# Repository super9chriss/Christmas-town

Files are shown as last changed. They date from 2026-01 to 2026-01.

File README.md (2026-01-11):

# "Smart"christmas town
A ESP32 C6 based Christmas town which connects to homeautomation to be able to remotly turn on and off the christmas lights
<div align="center">
  

</div>

## Features

* **Microcontroller:** ESP32-C6-Zero
* **Power Input:** 12V DC
* **supported** it works with 3 3V, 2 4.5V and one 12V houses/street lights but you can add more or use less based on youre christmas town
* **Connectivity:** USB-C receptacle for easy firmware flashing.

## PCB and schematic
| **PCB Layout** | **Schematic** |
| :---: | :---: |
||

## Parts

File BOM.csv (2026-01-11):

Description | quantity | price | link
LCSC parts | 1 | 3.71 + 3 (handeling) | see under here
esp32-c6 | 1 | 5.99 | https://nl.aliexpress.com/item/1005007349377720.html?mp=1
12V adapter | 1 | 2.62 | http://nl.aliexpress.com/item/1005007264933490.html?mp=1
PCB | 1 | 3.01 | https://cart.jlcpcb.com/quote?stencilLayer=2&stencilWidth=100&stencilLength=100&stencilCounts=5&plateType=1
 | total: | ? 18.33 ÷ $22
LCSC parts:
Index | LCSC# | MPN | Manufacturer | Package | Customer # | Description | RoHS | Quantity | MOQ | Multiple | Unit Price(?) | Extended Price(?) | Product Link
1 | C85864 | GCM188R71H104KA57D | muRata | 603 | C3,C6 | 100nF ñ10% 50V Ceramic Capacitor X7R 0603 | yes | 50 | 50 | 50 | 0.0096 | 0.48 | https://www.lcsc.com/product-detail/C85864.html
2 | C55722 | 0603CG101F500NT | FH | 603 | C4,C7 | 100pF ñ1% 50V Ceramic Capacitor C0G 0603 | yes | 50 | 50 | 50 | 0.0089 | 0.45 | https://www.lcsc.com/product-detail/C55722.html
3 | C95204 | RT0603BRD0710KL | YAGEO | 603 | R2,R4 | 100mW 10kê 75V Thin Film Resistor ñ25ppm/? ñ0.1% 0603 Chip Resistor - Surface Mount RoHS | yes | 20 | 20 | 20 | 0.0188 | 0.38 | https://www.lcsc.com/product-detail/C95204.html
4 | C70225 | 0603X106K160NT | FH | 603 | C1,C5 | 10uF ñ10% 16V Ceramic Capacitor X5R 0603 | yes | 10 | 10 | 10 | 0.0196 | 0.2 | https://www.lcsc.com/product-detail/C70225.html
5 | C142104 | LVS808040-100M-N | Chilisin | SMD,8x8mm | L1,L2 | 3.42A 10uH ñ20% 49.4mê Magnetic Shielded Inductor SMD,8x8mm Fixed Inductors RoHS | yes | 5 | 5 | 5 | 0.0997 | 0.5 | https://www.lcsc.com/product-detail/C142104.html
6 | C21190 | 0603WAF1001T5E | UNI-ROYAL | 603 | R5,R6,R7,R8 | 1kê ñ1% 100mW 0603 Thick Film Resistor | yes | 100 | 100 | 100 | 0.0011 | 0.11 | https://www.lcsc.com/product-detail/C21190.html
7 | C60077 | 0603X226M100NT | FH | 603 | C2,C2.1,C2.2,C8 | 22uF ñ20% 10V Ceramic Capacitor X5R 0603 | yes | 10 | 10 | 10 | 0.0143 | 0.14 | https://www.lcsc.com/product-detail/C60077.html
8 | C22967 | 0603WAF2702T5E | UNI-ROYAL | 603 | R3 | 27kê ñ1% 100mW 0603 Thick Film Resistor | yes | 100 | 100 | 100 | 0.0012 | 0.12 | https://www.lcsc.com/product-detail/C22967.html
9 | C23196 | 0603WAF5102T5E | UNI-ROYAL | 603 | R1 | 51kê ñ1% 100mW 0603 Thick Film Resistor | yes | 100 | 100 | 100 | 0.0011 | 0.11 | https://www.lcsc.com/product-detail/C23196.html
10 | C2071868 | AP63200WU-7 | DIODES | TSOT-23-6 | U1,U2 | 500kHz Buck Adjustable 2A TSOT-23-6 Voltage Regulators - DC DC Switching Regulators RoHS | yes | 2 | 1 | 1 | 0.3471 | 0.69 | https://www.lcsc.com/product-detail/C2071868.html
11 | C118536 | 2N2222A | ST(Semtech) | TO-92 | Q1,Q2,Q3,Q4 | Bipolar (BJT) Transistor NPN 40V 600mA 250MHz 625mW Through Hole TO-92 | yes | 20 | 20 | 20 | 0.0264 | 0.53 | https://www.lcsc.com/product-detail/C118536.html

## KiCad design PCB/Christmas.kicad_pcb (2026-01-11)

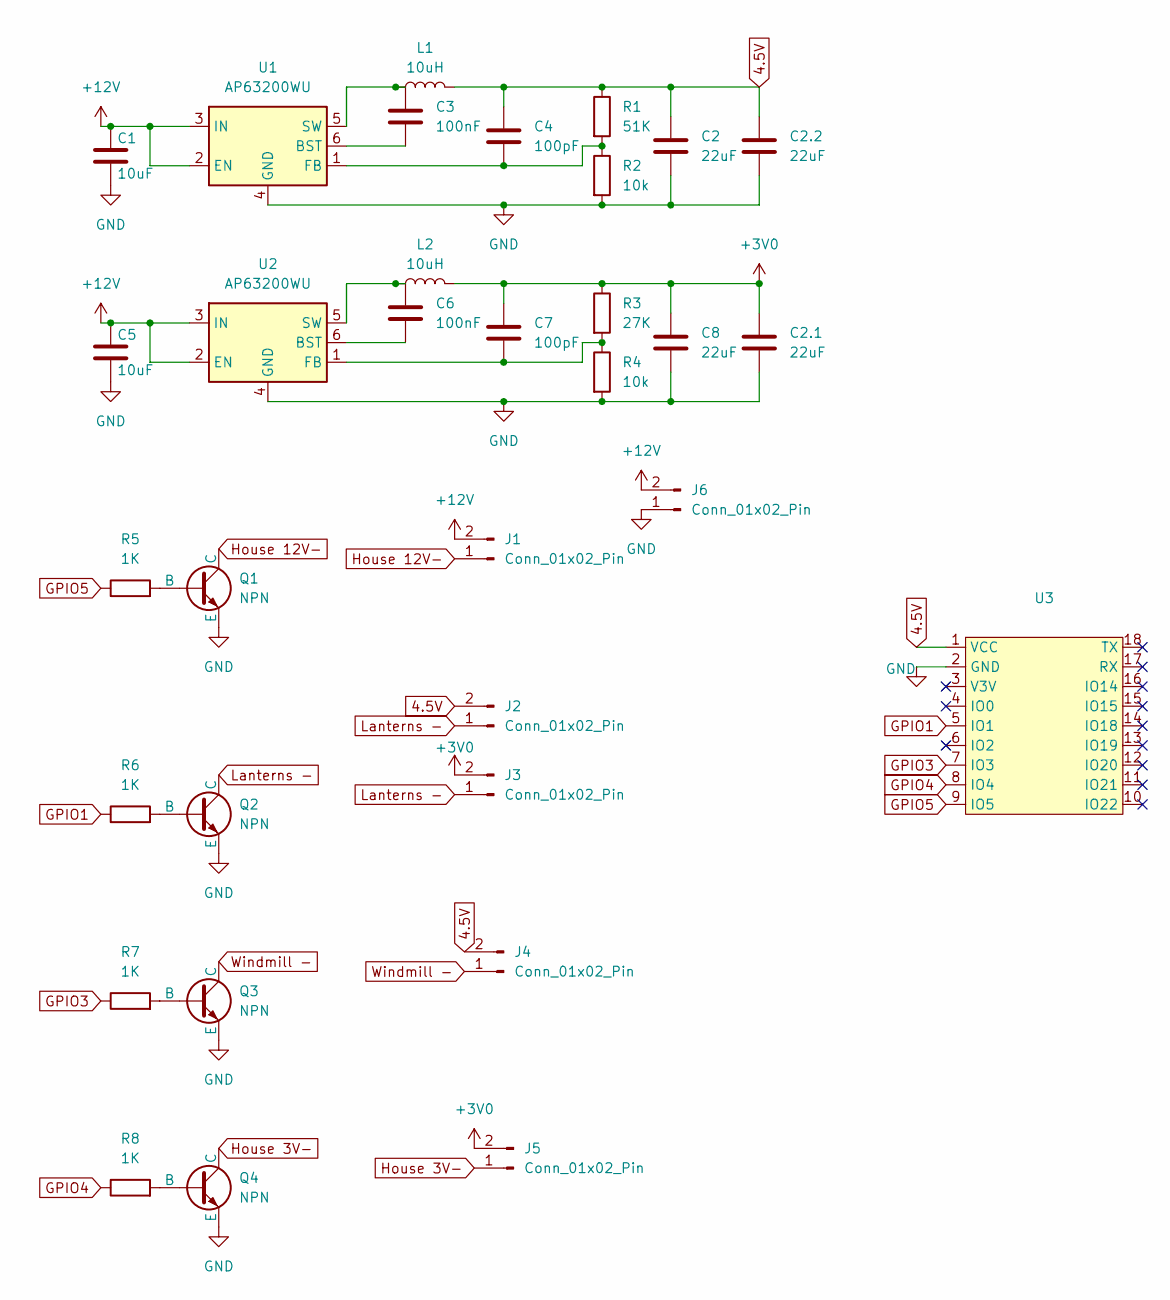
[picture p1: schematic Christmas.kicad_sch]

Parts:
C1, C5: 10uF; C_0603_1608Metric
C2, C2.1, C2.2, C8: 22uF; C_0603_1608Metric
C3, C6: 100nF; C_0603_1608Metric
C4, C7: 100pF; C_0603_1608Metric
J1, J2, J3, J4, J5, J6: Conn_01x02_Pin; SolderWire-0.1sqmm_1x02_P3.6mm_D0.4mm_OD1mm
L1, L2: 10uH; L_Bourns-SRN8040_8x8.15mm
Q1, Q2, Q3, Q4: NPN; TO92254P470H750-3
R1: 51K; R_0603_1608Metric
R2, R4: 10k; R_0603_1608Metric
R3: 27K; R_0603_1608Metric
R5, R6, R7, R8: 1K; R_0603_1608Metric
U1, U2: AP63200WU; TSOT-23-6_HandSoldering
U3: Waveshare-ESP32-C6-Zero

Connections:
4.5V: C2.1, C2.2.1, C4.1, J2.2, J4.2, L1.2, R1.1, U3.1 (VCC)
+3V0: C2.1.1, C7.1, C8.1, J3.2, J5.2, L2.2, R3.1
+12V: C1.1, C5.1, J1.2, J6.2, U1.2 (EN), U1.3 (IN), U2.2 (EN), U2.3 (IN)
GND: C1.2, C2.2, C2.1.2, C2.2.2, C5.2, C8.2, J6.1, Q1.3 (E), Q2.3 (E), Q3.3 (E), Q4.3 (E), R2.2, R4.2, U1.4 (GND), U2.4 (GND), U3.2 (GND)
GPIO1: R6.1, U3.5 (IO1)
GPIO3: R7.1, U3.7 (IO3)
GPIO4: R8.1, U3.8 (IO4)
GPIO5: R5.1, U3.9 (IO5)
House 3V-: J5.1, Q4.1 (C)
House 12V-: J1.1, Q1.1 (C)
Lanterns -: J2.1, J3.1, Q2.1 (C)
unnamed: Q1.2 (B), R5.2
unnamed: Q2.2 (B), R6.2
unnamed: Q3.2 (B), R7.2
unnamed: Q4.2 (B), R8.2
unnamed: C3.2, U1.6 (BST)
unnamed: C4.2, R1.2, R2.1, U1.1 (FB)
unnamed: C3.1, L1.1, U1.5 (SW)
unnamed: C6.2, U2.6 (BST)
unnamed: C7.2, R3.2, R4.1, U2.1 (FB)
unnamed: C6.1, L2.1, U2.5 (SW)
Windmill -: J4.1, Q3.1 (C)

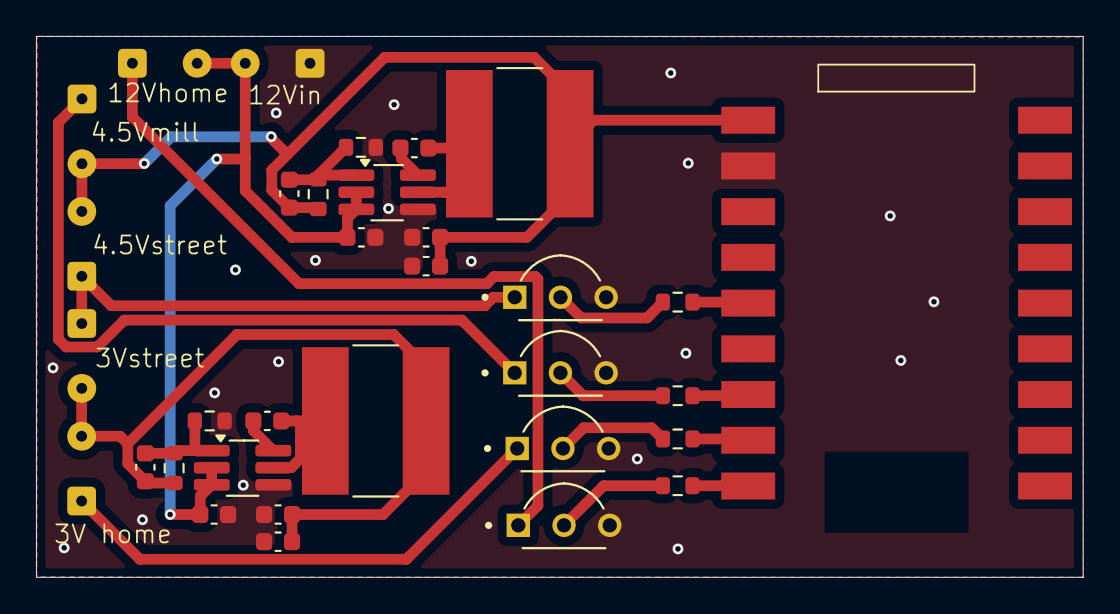
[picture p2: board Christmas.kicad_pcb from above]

Board: 2 copper layers, 58.2 x 30.1 mm, 33 parts (0 on the bottom side), 22 nets.

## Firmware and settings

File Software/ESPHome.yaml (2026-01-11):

esphome:
  name: christmas-village-controller
  friendly_name: Christmas Village Controller

esp32:
  board: esp32-c6-devkitm-1 
  variant: esp32c6
  framework:
    type: esp-idf
    version: 5.3.1 


wifi:
  ssid: "name"
  password: "ww"

api:
ota:
  - platform: esphome

switch:
  - platform: gpio
    pin: GPIO5
    name: "12V house"
    id: house_12v
    restore_mode: RESTORE_DEFAULT_OFF

  - platform: gpio
    pin: GPIO1
    name: "street light (3V & 4.5V)"
    id: lanterns_mix
    restore_mode: RESTORE_DEFAULT_OFF

  - platform: gpio
    pin: GPIO3
    name: "windmill (4.5V)"
    id: windmill
    restore_mode: RESTORE_DEFAULT_OFF

  - platform: gpio
    pin: GPIO4
    name: "3V house"
    id: house_3v
    restore_mode: RESTORE_DEFAULT_OFF
